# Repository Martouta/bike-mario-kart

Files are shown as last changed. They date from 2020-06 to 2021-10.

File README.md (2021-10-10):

# Bike Mario Kart Project
Play the Nintendo Switch racing game "Mario Kart 8 Deluxe" using a real bike.
[Project in Arduino Hub](https://create.arduino.cc/projecthub/Martouta/real-bike-mario-kart-8-deluxe-f6537f)

## Setup
Using a Linux OS with Arduino IDE 1.6.6 (or above). for Mac it must be very similar. For Windows not so much but it must be doable anyway.
For now only for Arduino Leonardo and not any other microcontroller.

### External libraries
These are the libraries that you need to download:
- [SwitchJoystick](https://github.com/HackerLoop/Arduino-JoyCon-Library-for-Nintendo-Switch)
- [MPU6050](https://github.com/jrowberg/i2cdevlib/tree/master/Arduino/MPU6050)
- [I2Cdev](https://github.com/jrowberg/i2cdevlib)

### Physical Requirements
- A real bicycle.
- A stationary stand for the back wheel. Make sure that it has like a small 'wheel' of steel or any other material where you can put a magnet on it. I also strongly recommend that it is one of those with noise reduction.
- A neodymium magnet.
- A hall effect sensor. Personally, I have `KY-003` which also contains a `voltage regulator` so it works with any voltage from 3.3V to 5V. For the circuit I may assume that you have a voltage regulator too.
- A `MPU6050`. Technically, any 6 axis accelerometer sensor (which contains an _accelerometer_ and a _gyroscope_) would do, but your would need to adapt the code if it is not a `MPU6050`. Personally, I use the `GY-521`, which is a `MPU6050` with a voltage regulator to work with any voltage from 3.3V to 5V. For the circuit I may assume that you have a voltage regulator too. You can buy it soldered (in 1 piece) or solder it yourself.
- An Arduino Leonardo.
- An AC adapter of 9V for the Arduino.
- 4 small breadboards and 1 big one as well.
- 5 push buttons of 4 legs each.
- 3 LEDs.
- 3 Resistors of 330Ω and 5 resistors of 10KΩ (although 5KΩ might be enough).
- Cables to connect everything together. This can be done in many different ways but I bought long cables and cut them and strip them myself with the right size to then stick them to the big with some sticky tapes.
- A Nintendo Switch. In my case with the Dock as well.
- The game "Mario Kart 8 Deluxe" for the console.
- USB cable of A type to connect to the laptop and micro type to connect to the Arduino. Then, I use the same cable to connect the Arduino to the Dock, but if you do not have the Dock, I guess that you will need an adapter or another cable to connect it directly to the Switch (which uses C type).
- Joystick (usually sold as the one of the PS2).
- SPTD Switch interruptor.

### Circuit
General schematics:
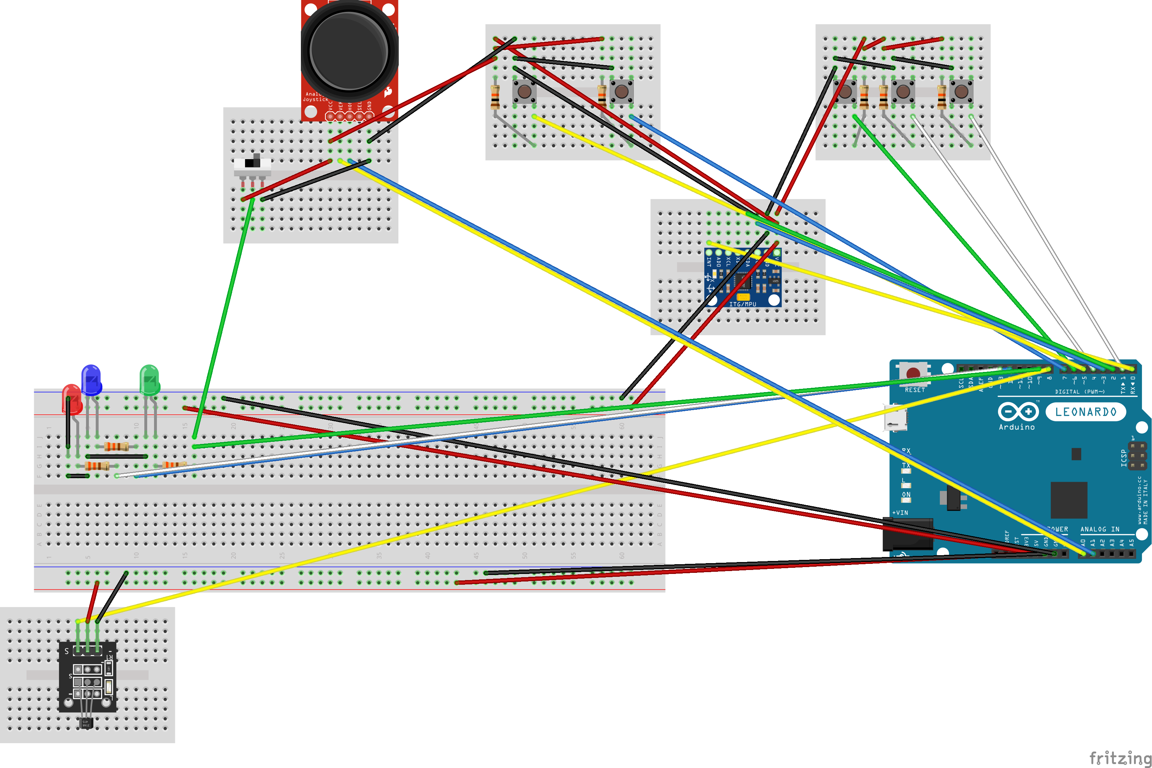
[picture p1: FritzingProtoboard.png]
Fritzing Circuit

You can also [download the file for Fritzing (release v1.0.0)](https://fritzing.org/media/fritzing-repo/projects/r/real-bike-mario-kart-8-deluxe/fritzing/bike.fzz) with more details of the schematics in the [Fritzing Project site](https://fritzing.org/projects/real-bike-mario-kart-8-deluxe).
The most recent version is in this same project, in the file `bike.fzz`.

In the front side there are the _GY-521_ almost right in the middle of the rotation (or at least enough like to detect the rotation well) and the buttons.
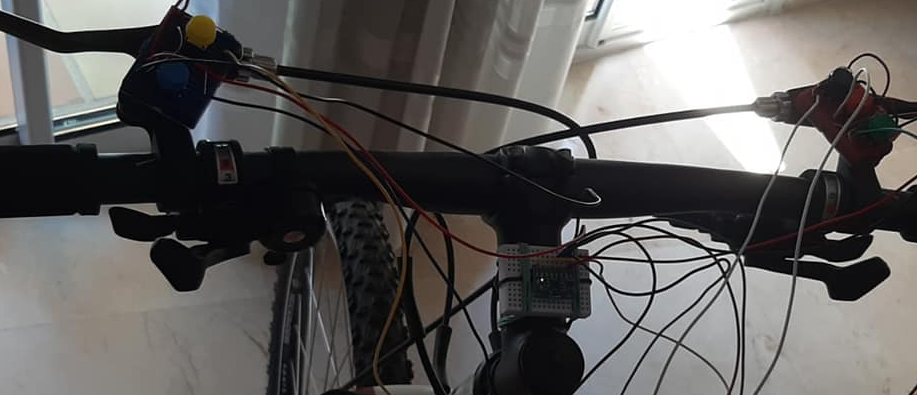
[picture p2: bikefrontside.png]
Bike front side


In the back side there is everything else in my case, but most of it doesn't matter where you put it, except for the magnet and the _hall effect sensor_ that must stay there in the back to detect the speed.
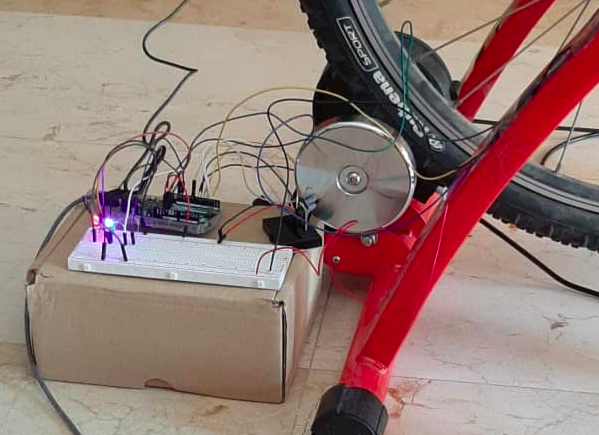
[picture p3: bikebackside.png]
Bike back side


It is not obvious but in that grey/silver small 'wheel'/circle, that spins when the real bike wheel does, there is a small magnet that I neodymium added.
What you see very close to it is the _hall effect sensor_, that detects when the magnet is in front of it and when it isn't. The red LED of the circuit should have light only when the magnet is being detected (outside of 'startup time' tho, when you are already playing :wink: ).

### How to upload the code
Download this code from Github. Put everything in a folder with the name `bike`. Wherever you want to locate that folder should work.

Install the [Arduino IDE](https://www.arduino.cc/en/main/software). It must be the version 1.6.6 or above.

Create the sketchbook folder from the terminal and add the necessary config by typing the following commands in the _Terminal_.
That is being `32` in my case the hightest number I see in `ls /snap/arduino/`.
Not sure if the last command is necessary or a bad idea, so I recommend trying without it first.
```
mkdir -p ~/snap/arduino/switch/Arduino/libraries
sudo cp -R /snap/arduino/32/hardware ~/snap/arduino/switch/Arduino/.
sudo chown -R $USER:$USER ~/snap/arduino/switch/Arduino/hardware
sudo chmod 777 ~/snap/arduino/switch/Arduino/hardware/boards.txt
```

Add the external libraries that you downloaded with their respective folders (the folders must have the same name of the name of the library as mentioned above) inside `~/snap/arduino/switch/Arduino/libraries`.

In the Arduino IDE, go to `File -> Preferences` and change the `Sketchbook location` to be `~/snap/arduino/switch/Arduino`.

Add this at the end of `~/snap/arduino/switch/Arduino/hardware/boards.txt` using any text editor (vi, nano, emacs, gedit, atom, sublime, etc.):
```
##############################################################

nintendoSwitch.name=SwitchJoystick
nintendoSwitch.vid.0=0x0F0D
nintendoSwitch.pid.0=0x8092
nintendoSwitch.vid.1=0x0F0D
nintendoSwitch.pid.1=0x0092

nintendoSwitch.upload.tool=avrdude
nintendoSwitch.upload.protocol=avr109
nintendoSwitch.upload.maximum_size=28672
nintendoSwitch.upload.maximum_data_size=2560
nintendoSwitch.upload.speed=57600
nintendoSwitch.upload.disable_flushing=true
nintendoSwitch.upload.use_1200bps_touch=true
nintendoSwitch.upload.wait_for_upload_port=true

nintendoSwitch.bootloader.tool=avrdude
nintendoSwitch.bootloader.low_fuses=0xff
nintendoSwitch.bootloader.high_fuses=0xd8
nintendoSwitch.bootloader.extended_fuses=0xcb
nintendoSwitch.bootloader.file=caterina/Caterina-Leonardo.hex
nintendoSwitch.bootloader.unlock_bits=0x3F
nintendoSwitch.bootloader.lock_bits=0x2F

nintendoSwitch.build.mcu=atmega32u4
nintendoSwitch.build.f_cpu=16000000L
nintendoSwitch.build.vid=0x0F0D
nintendoSwitch.build.pid=0x0092
nintendoSwitch.build.usb_product="POKKEN CONTROLLER"
nintendoSwitch.build.board=AVR_LEONARDO
nintendoSwitch.build.core=arduino
nintendoSwitch.build.variant=leonardo
nintendoSwitch.build.extra_flags={build.usb_flags}

```

Replace inside `~/snap/arduino/switch/Arduino/hardware/platform.txt` the line `build.usb_manufacturer="Unknown"` with `build.usb_manufacturer="HORI CO.,LTD."`.

Close and open again the Arduino IDE so it can read the changes made in the previous steps when it starts up.
Open the file `bike.ino` of this code that you downloaded and saved inside a folder called `bike`.

In the Arduino IDE, Go to `Tools` and select the board _SwitchJoystick_. Then, select the programmer `Arduino as ISP (ATmega32U4)`.

You may need to do this from the _Terminal_ to have permissions:
```
sudo usermod -a -G dialout $USER
sudo systemctl stop ModemManager.service
sudo systemctl disable ModemManager.service
```

Keep your finger pressing the "reset" button of your Arduino Leonardo while you press once (not keeping pressed) the "Upload" button in the Arduino IDE. Release the "reset" button as soon as you see in the IDE "Uploding ...".

If it works, at the end of the upload, you should see a message similar to this one:

> avrdude: 16824 bytes of flash verified  
> avrdude done.  Thank you.

## How to play
First, you need to know how to play the game itself with the JoyCons. There are many good tutorials out there, but this is how to play in a nutshell:
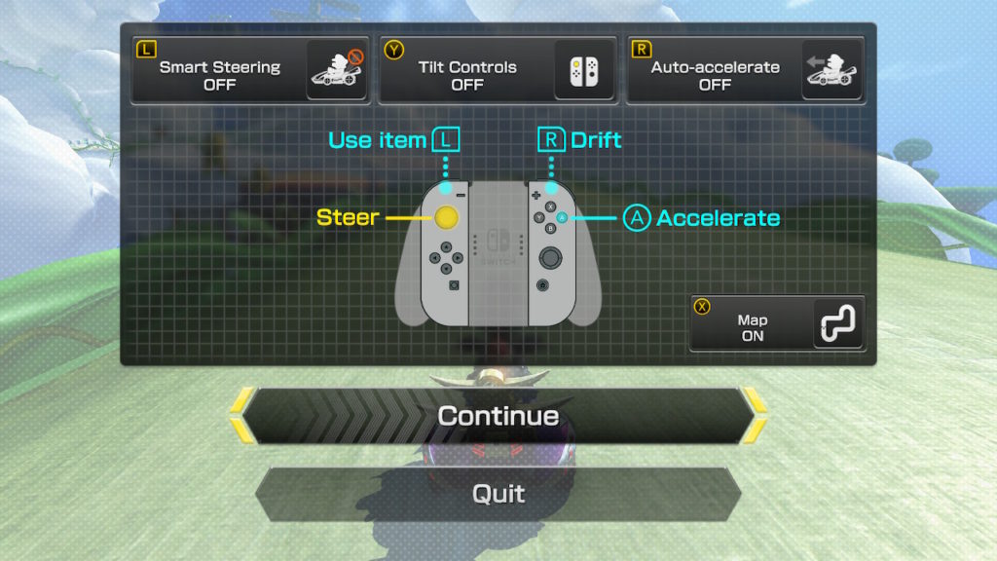
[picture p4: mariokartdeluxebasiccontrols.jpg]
Mario Kart 8 Deluxe Basic Controls


As for playing with this sketch/code, you will need the JoyCon(s) to select the game in the Nintendo Switch and navigate in the menus and these things.
When you want the Arduino to start sending data to your Nintendo Switch, press the button equivalent to the A from the bike. After that, you will be able to play from the bike :smile:.

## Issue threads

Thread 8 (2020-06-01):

Solder the front buttons, resistors and cables using a permanent protoboard

Martouta, 2020-06-01:
In the middle of a race, the L button literally got out of the protoboard to stay on my sweated finger :joy:

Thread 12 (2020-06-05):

Improve the documentation

Martouta, 2020-06-05:
Based on suggestions of a friend and a bit of what I see myself. There are some improvements here to be made.

1. The images must be saved in a folder because there will be many more and otherwise this will be pure chaos.
2. Better to see a close-up pic of the buttons on the bike. A couple more pics and two/three sentences would be enough.
3. The image of the schematic exported by Fritzing is not clear enough, and much less if the circuit grows, so I will have to draw something better as well to make it easier to follow.
4. Some pics of the bike need more light.
5. Explain why there are multiple .ino files but they only need to import one.
6. Circuit description in its own file.

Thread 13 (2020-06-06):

Add "How-to" for Windows and Mac as well :)

Martouta, 2020-06-06:
So far the documentation is only for Linux.

Martouta, 2020-08-01:
### Starting for Mac ☺️

1. Download the code & extract & name the folder "bike"
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

2. Download libraries

helper 1:
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

helper 2:
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

3. Install Arduino IDE
It must be the version 1.6.6 or above.

4. Check where the hardware folder is
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
`/Applications/Arduino.app/Contents/Java/hardware/arduino/avr `

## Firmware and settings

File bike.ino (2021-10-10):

#include "config.h"

#ifdef JOYSTICKSHIELD
  #define pinButtonR      (uint8_t)2 // Up button
  #define pinButtonA      (uint8_t)3 // Right button
  #define pinButtonB      (uint8_t)4 // Down button
  #define pinButtonL      (uint8_t)5 // Left button
  #define pinButtonAdd    (uint8_t)7 // F button
  #define pinHallSensor   (uint8_t)13
#else
  #define pinInterruptMPU (uint8_t)0
  #define pinButtonB      (uint8_t)1
  // Pins 2 and 3 and for SCA and SCL of the MPU6050
  #define pinButtonA      (uint8_t)4
  #define pinButtonAdd    (uint8_t)5
  #define pinButtonR      (uint8_t)6
  #define pinButtonL      (uint8_t)7
  #define pinHallSensor   (uint8_t)8
  #define pinSPTDLeftJS   (uint8_t)9
  #define pinRotationLED  (uint8_t)12
  #define pinSpeedLED     (uint8_t)13
#endif

const uint8_t buttons[] = { pinButtonR, pinButtonA, pinButtonB, pinButtonL, pinButtonAdd };
#define pinLAnalogX    (uint8_t)A0
#define pinLAnalogY    (uint8_t)A1


#include <I2Cdev.h>
#include <MPU6050_6Axis_MotionApps20.h>
#include <Wire.h>

#include <SwitchJoystick.h>

boolean gameStarted = false;

void setup() {
  for (int i = 0; i < 5; i++) pinMode(buttons[i], INPUT_PULLUP); // TODO: check what this implies when it isn't using the JoystickShield

  #ifndef JOYSTICKSHIELD
    // pinMode(pinLAnalogX, INPUT); // TODO: check what this implies when it isn't using the JoystickShield
    // pinMode(pinLAnalogY, INPUT); // TODO: check what this implies when it isn't using the JoystickShield
    pinMode(pinSPTDLeftJS, INPUT);

    pinMode(pinSpeedLED, OUTPUT);
    pinMode(pinRotationLED, OUTPUT);

    i2cSetup();
    MPU6050Connect();
  #endif

  pinMode(pinHallSensor, INPUT);
  resetFrequency();
  initializeSwitch();

  #ifndef JOYSTICKSHIELD
    updateLEDsGameUnstarted();
  #endif
}

void loop() {
  // Wait for the A button to start playing.
  if (gameStarted) {
    updateGameData();
    sendGameData();
    delay(50);
  } else {
    updateGameStarted();
    delay(100);
  }
}

void updateGameStarted() {
  gameStarted = checkGameStarted();
  #ifndef JOYSTICKSHIELD
    updateLEDsGameStarted(gameStarted);
  #endif
}

boolean checkGameStarted() {
  return (digitalRead(pinButtonA) == LOW);
}

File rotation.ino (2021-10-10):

// Thanks to https://forum.arduino.cc/index.php?topic=408851.msg2813515#msg2813515

#ifndef JOYSTICKSHIELD
  MPU6050 mpu;

  struct MPU_INFO {
    int xa;
    int ya;
    int za;
    int xg;
    int yg;
    int zg;
  };
  const struct MPU_INFO offsets = { .xa = 2192, .ya = -506, .za = 595, .xg = 114, .yg = 23, .zg = -5 };

  // ================================================================
  // ===               INTERRUPT DETECTION ROUTINE                ===
  // ================================================================
  volatile bool mpuInterrupt = false;     // indicates whether MPU interrupt pin has gone high
  void dmpDataReady() {
    mpuInterrupt = true;
  }

  // ================================================================
  // ===                      MPU DMP SETUP                       ===
  // ================================================================
  int FifoAlive = 0; // tests if the interrupt is triggering
  int IsAlive = -20;     // counts interrupt start at -20 to get 20+ good values before assuming connected
  // MPU control/status vars
  uint8_t mpuIntStatus;   // holds actual interrupt status byte from MPU
  uint8_t devStatus;      // return status after each device operation (0 = success, !0 = error)
  uint16_t packetSize;    // expected DMP packet size (default is 42 bytes)
  uint16_t fifoCount;     // count of all bytes currently in FIFO
  uint8_t fifoBuffer[64]; // FIFO storage buffer

  // orientation/motion vars
  Quaternion q;           // [w, x, y, z]         quaternion container
  VectorInt16 aa;         // [x, y, z]            accel sensor measurements
  VectorInt16 aaReal;     // [x, y, z]            gravity-free accel sensor measurements
  VectorInt16 aaWorld;    // [x, y, z]            world-frame accel sensor measurements
  VectorFloat gravity;    // [x, y, z]            gravity vector
  float euler[3];         // [psi, theta, phi]    Euler angle container
  float ypr[3];           // [yaw, pitch, roll]   yaw/pitch/roll container and gravity vector
  //float Yaw; // in degrees



  void MPU6050Connect() {
    static int MPUInitCntr = 0;
    // initialize device
    mpu.initialize(); // same
    // load and configure the DMP
    devStatus = mpu.dmpInitialize();// same

    if (devStatus != 0) {
      // ERROR!
      // 1 = initial memory load failed
      // 2 = DMP configuration updates failed
      // (if it's going to break, usually the code will be 1)

      MPUInitCntr++;

      if (MPUInitCntr >= 10) return; //only try 10 times
      delay(1000);
      MPU6050Connect(); // Lets try again
      return;
    }

    mpu.setXAccelOffset(offsets.xa);
    mpu.setYAccelOffset(offsets.ya);
    mpu.setZAccelOffset(offsets.za);
    mpu.setXGyroOffset(offsets.xg);
    mpu.setYGyroOffset(offsets.yg);
    mpu.setZGyroOffset(offsets.zg);

    mpu.setDMPEnabled(true);

    attachInterrupt(digitalPinToInterrupt(pinInterruptMPU), dmpDataReady, FALLING); // Enabling interrupt detection

    mpuIntStatus = mpu.getIntStatus(); // Same
    // get expected DMP packet size for later comparison
    packetSize = mpu.dmpGetFIFOPacketSize();
    delay(1000); // Let it Stabalize
    mpu.resetFIFO(); // Clear fifo buffer
    mpu.getIntStatus();
    mpuInterrupt = false; // wait for next interrupt
  }
  // ================================================================
  // ===                      i2c SETUP Items                     ===
  // ================================================================
  void i2cSetup() {
    // join I2C bus (I2Cdev library doesn't do this automatically)
  #if I2CDEV_IMPLEMENTATION == I2CDEV_ARDUINO_WIRE
    Wire.begin();
    TWBR = 24; // 400kHz I2C clock (200kHz if CPU is 8MHz)
  #elif I2CDEV_IMPLEMENTATION == I2CDEV_BUILTIN_FASTWIRE
    Fastwire::setup(400, true);
  #endif
  }


  float getYaw() {
    updateRotationAngles();
    //return Yaw;
    return (float) ypr[0];
  }


  void updateRotationAngles() {
    if (!mpuInterrupt) { return; }

    mpuInterrupt = false;
    FifoAlive = 1;
    fifoCount = mpu.getFIFOCount();
    /*
    fifoCount is a 16-bit unsigned value. Indicates the number of bytes stored in the FIFO buffer.
    This number is in turn the number of bytes that can be read from the FIFO buffer and it is
    directly proportional to the number of samples available given the set of sensor data bound
    to be stored in the FIFO
    */

    // PacketSize = 42; refference in MPU6050_6Axis_MotionApps20.h Line 527
    // FIFO Buffer Size = 1024;
    uint16_t MaxPackets = 20;// 20*42=840 leaving us with  2 Packets (out of a total of 24 packets) left before we overflow.
    // If we overflow the entire FIFO buffer will be corrupt and we must discard it!

    // At this point in the code FIFO Packets should be at 1 99% of the time if not we need to look to see where we are skipping samples.
    if ((fifoCount % packetSize) || (fifoCount > (packetSize * MaxPackets)) || (fifoCount < packetSize)) { // we have failed Reset and wait till next time!
      updateRotationLed(); // lets turn off the blinking light so we can see we are failing.

      mpuIntStatus = mpu.getIntStatus(); // reads MPU6050_RA_INT_STATUS       0x3A
      // MPU6050_RA_INT_STATUS       0x3A
      //
      // Bit7, Bit6, Bit5, Bit4          , Bit3       , Bit2, Bit1, Bit0
      // ----, ----, ----, FIFO_OFLOW_INT, I2C_MST_INT, ----, ----, DATA_RDY_INT

      /*
      Bit4 FIFO_OFLOW_INT: This bit automatically sets to 1 when a FIFO buffer overflow interrupt has been generated.
      Bit3 I2C_MST_INT: This bit automatically sets to 1 when an I2C Master interrupt has been generated. For a list of I2C Master interrupts, please refer to Register 54.
      Bit1 DATA_RDY_INT This bit automatically sets to 1 when a Data Ready interrupt is generated.
      */

      //I2C_MST_STATUS
      //PASS_THROUGH, I2C_SLV4_DONE,I2C_LOST_ARB,I2C_SLV4_NACK,I2C_SLV3_NACK,I2C_SLV2_NACK,I2C_SLV1_NACK,I2C_SLV0_NACK,
      mpu.resetFIFO();// clear the buffer and start over
      mpu.getIntStatus(); // make sure status is cleared we will read it again.
    } else {
      while (fifoCount  >= packetSize) { // Get the packets until we have the latest!
        if (fifoCount < packetSize) break; // Something is left over and we don't want it!!!
        mpu.getFIFOBytes(fifoBuffer, packetSize); // lets do the magic and get the data
        fifoCount -= packetSize;
      }
      calcAngles();
      blinkRotationLed(); // Blink the Light
      if (fifoCount > 0) mpu.resetFIFO(); // Should never happen! but lets start fresh if we need to.
    }
  }


  void calcAngles() {
    mpu.dmpGetQuaternion(&q, fifoBuffer);
    mpu.dmpGetGravity(&gravity, &q);
    mpu.dmpGetYawPitchRoll(ypr, &q, &gravity);
    // Yaw = (ypr[0] * 180 / M_PI);
  }
#endif

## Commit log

2020-01-24 Turn ON and OFF the LED when the magnet is detected
2020-01-24 Calc RPS with println
2020-06-01 Share link to project in Arduino Hub
2020-06-04 More accurate Yaw to Joystick & Refactor to its own function
2020-06-05 Switch & LED on ? Use manual JS : Use bike rotation or stay in center
2020-06-06 Update README components and fritzing + Upload fritizing file
    [bike.fzz]
2020-06-07 Use the hall sensor
2020-06-08 Define each pin as a type unsigned integer of length 8 bits
2020-06-13 [Refactor] Cleanup :) - Config file added. So far to define or not if using the JoystickShield. - LEDs information in its own file. Only defining the methods and calling them when they are gonna be u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
